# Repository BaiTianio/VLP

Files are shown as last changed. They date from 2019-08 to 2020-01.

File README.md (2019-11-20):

*As we know,VLP is a immature technolgy and involved not only software but hardware, so that's a really complicated project.In here, I just want to show my design for VLP. For others,I know this repository is diffcult to use and understand.If you can get it and interest it,you can contact me with the Issues.* 
# VLP（visible light positioning）
仓库文件目录：  
1.Document：文档 ;  
2.Data_Receive_Process:上位机数据接收和处理数据处理，包括MATLAB和Python,接收到的数据存储在Data子文件下; 
3.Receiver：接收器设计，包括SW模型设计、AD电路设计和STM32程序设计;    
4.Transmitter：发送端设计，包括电路设计和程序设计。

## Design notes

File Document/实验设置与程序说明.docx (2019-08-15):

一、实验:

1.实验设置

LED固定在(x=0cm, y=0cm, z=200cm)。分别将探测器放在:

坐标 | LED与探测器连线的夹角（angle）
(x=0cm, y=35.26cm, z=0cm) | 80°
… | …
(x=0cm, y=346.41cm, z=0cm) | 30°

角度(angle)=(30,31,…,44,45; 46,48,…,78,80).

2.数据处理程序及文件说明：

程序1：singlePD.m

功能：分别绘制单个PD（PD1-PD32），从angle=30°到angle=80°时变化情况。

图坐标：(x：angle从30到80度), (y: 对应光照度)。

生成文件：保存在(picuture/ SignlePD/)文件夹 ,命名规则PDx.jpg (x=1,2…,31,32)。

备注：每次取的是各个PD的最大值。

程序2：PDs8_V1.m

功能:分别绘制，4组PD{(1,5,…,25,29);..;(4,8,…,28,32)}分别在(angle=30,31,…)时的图像。

图坐标：(x：每组PD，1-8)。

生成文件：保存在(./picuture/ 8PDsV1/)文件夹 ,命名规则PDarrayk_l.jpg (k=1,2,3,4; l=angle)。

备注：寻找整个二维数组（确定angle和times了的一次数据）的最大值，然后每个PD取该最大值所在行。

程序3：PDs8_V2.m

功能: 同程序2。

图坐标：同程序2。

生成文件：保存在(./picuture/ 8PDsV2/)文件夹 ,命名规则PDarrayk_l.jpg (k=1,2,3,4; l=angle)。

备注：分别取每个PD所对应的最大值。

程序4：PDs32_V1.m

功能:分别绘制32个PD在(angle=30,31,…)时的图像。

图坐标：(x：32个 PD, 1-32)。

生成文件：保存在(./picuture/ 32PDsV1/)文件夹 ,命名规则Angle_l.jpg (l=angle)。

备注：同程序2

程序5：PDs32_V2.m

功能: 同程序4。

图坐标：同程序4。

生成文件：保存在(./picuture/ 32PDsV2/)文件夹 ,命名规则Angle_l.jpg (l=angle)。

备注：同程序3

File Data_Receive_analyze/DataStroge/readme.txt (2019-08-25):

当前目录命名规则：年_月_日
子目录命名规则：格式_备注，例csv_raw,表示文件为csv格式的原数据

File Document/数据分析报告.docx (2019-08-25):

目前要解决的有两个问题：

1.时间一致性

如果只有一个LED，则所有被照到的PD的数据最大值应出现在同一位置。该问题要解决的是水平角度测量准确性。

2.增益一致性

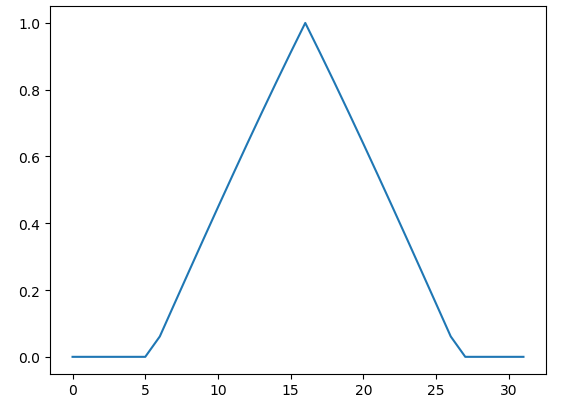
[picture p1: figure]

32个PD分布应该接近理想的分布曲线（图1）。该问题决定了俯仰角测量准确性。

图1 理想分布

一、问题1的分析

已知条件：

ADC时钟12MHz,采样时间239.5cycle，转换时间=采样时间+12.5cycle。每个通道的转换时间为(239.5+12.5)/12=21us。图2所示为不同PD采样时间分布，其中颜色条为以PD0为0时刻的延迟时间。由图可以看出32个PD转换完需要651us。32个PD转换完成后会进行数据发送给上位机，数据发送时间不确定。

图2 采集时间分布

数据分析：

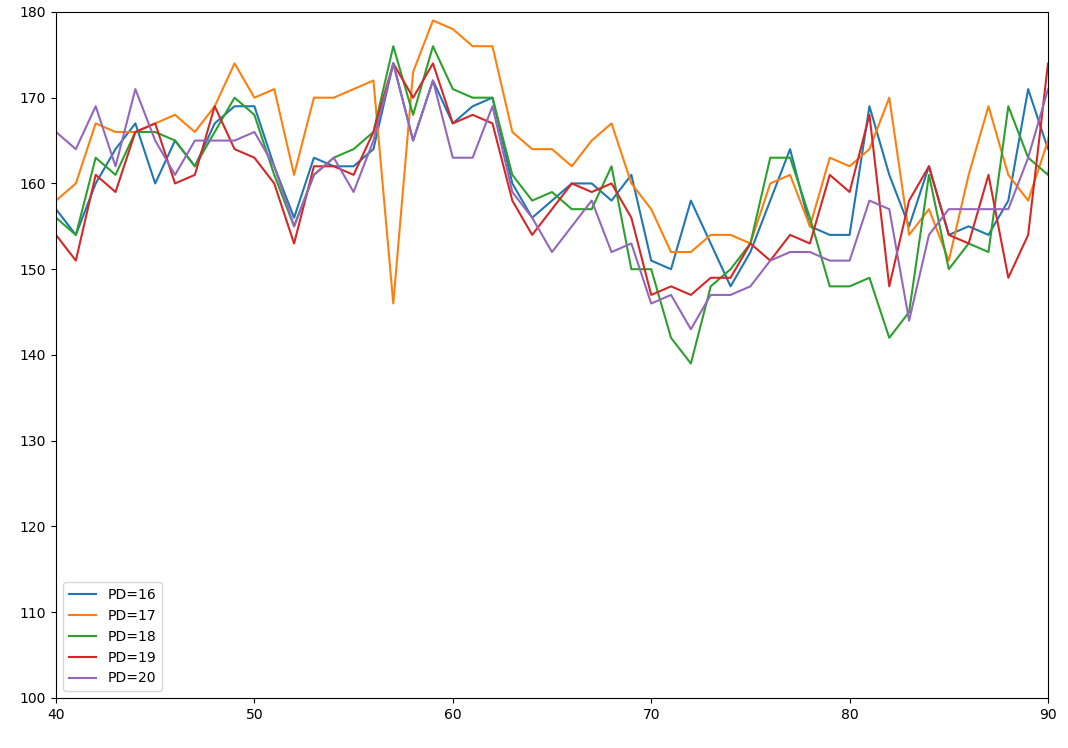
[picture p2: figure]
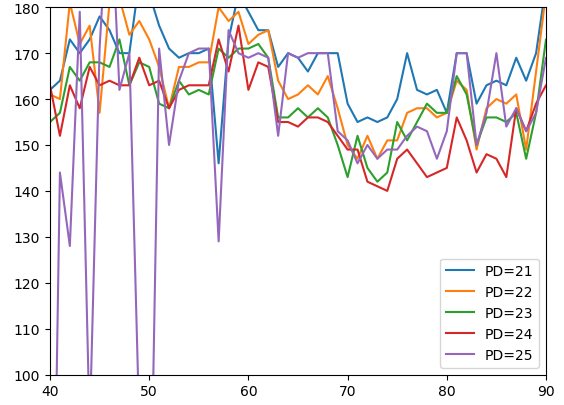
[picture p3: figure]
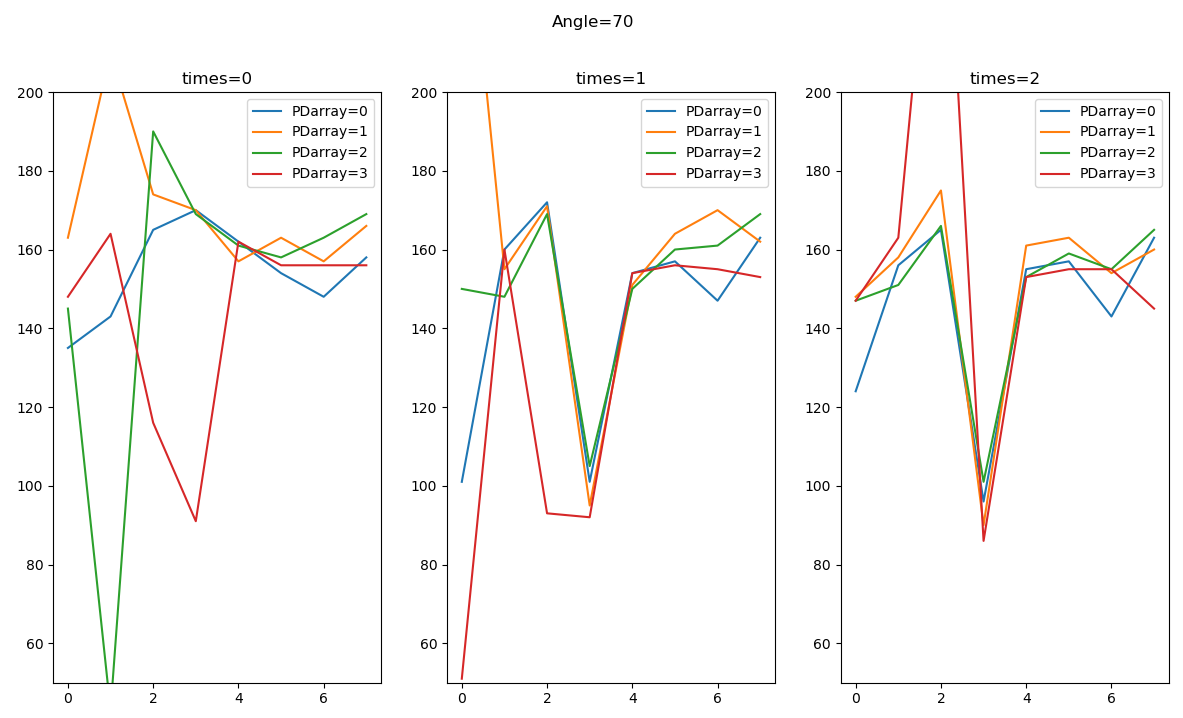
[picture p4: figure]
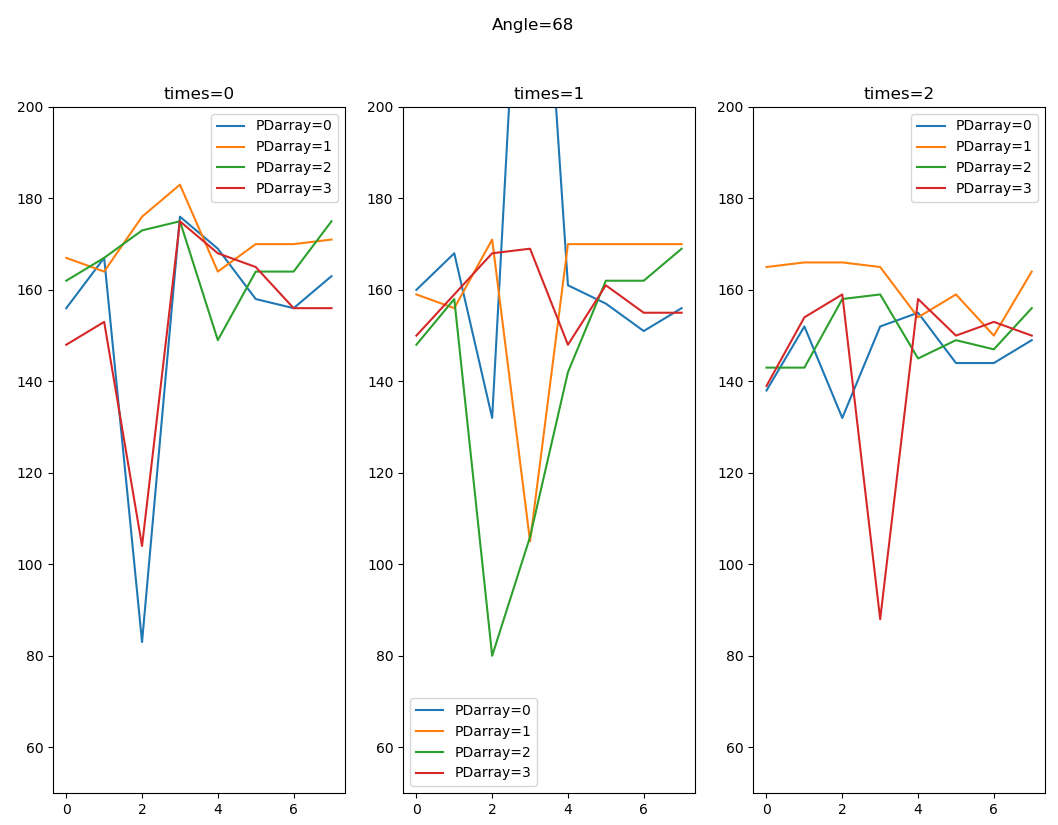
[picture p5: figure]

如图3所示，分别为68度时和70度时每组PD最大值所处的位置曲线。图4是单个PD在所有数据中的位置曲线。

图4 单个PD的在所有数据中的位置分布

图3 每组PD最大值位置曲线

根据图3、4可以看出，不同PD之间的关系比较明确，同一PD之间的变化关系不明确。以图3右图中PD21和PD22为例，PD21曲线处于PD22上方，分析原因有二：1.转换时间差的影响；2.PD朝向不同。

二、问题2的分析

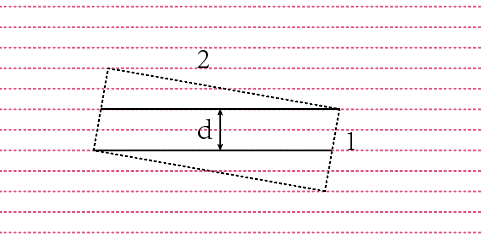
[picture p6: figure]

已知条件：图5是PD和其对应的角度关系。对PD受光照情况进行近似模拟，以图6中d的大小代表光照大小即可得出图一的分布曲线。

图5. PD与对应角度

图6. PD光照情况

数据分析：

图7分别为未调整增益和调整增益后的数据图。

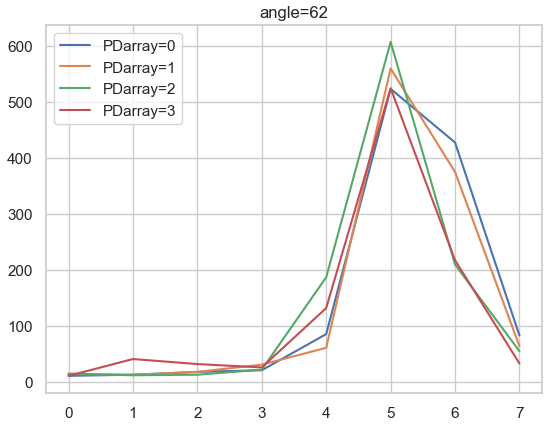
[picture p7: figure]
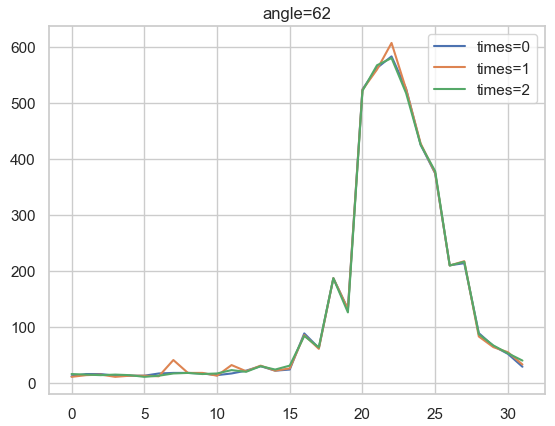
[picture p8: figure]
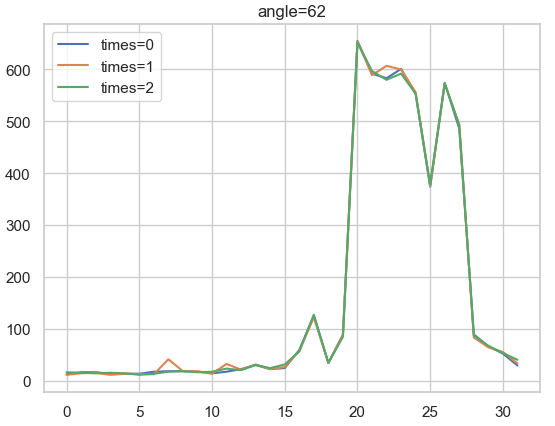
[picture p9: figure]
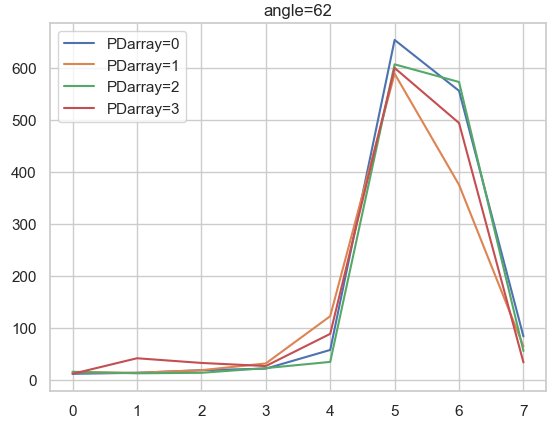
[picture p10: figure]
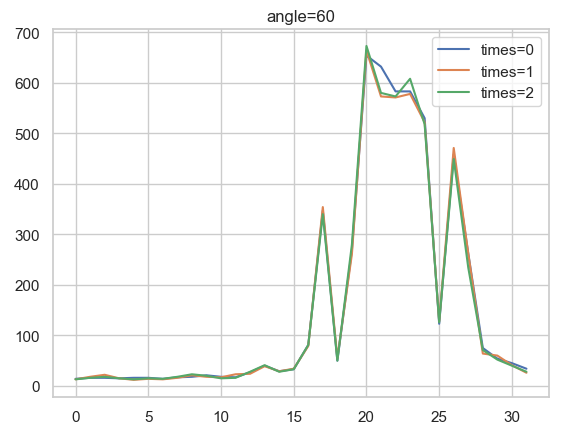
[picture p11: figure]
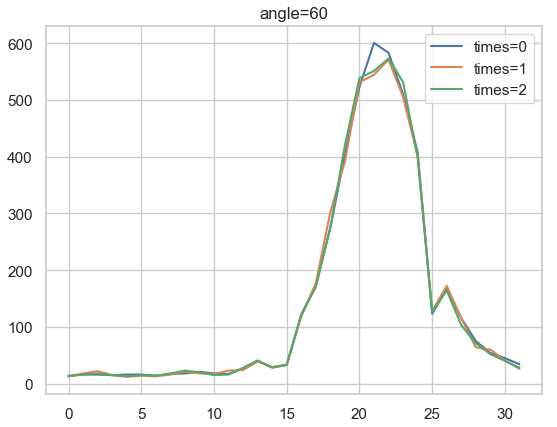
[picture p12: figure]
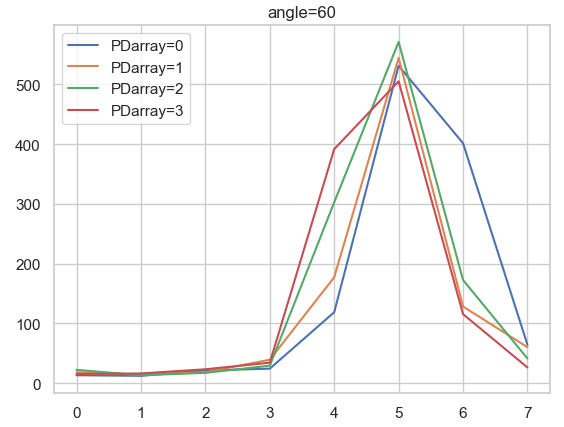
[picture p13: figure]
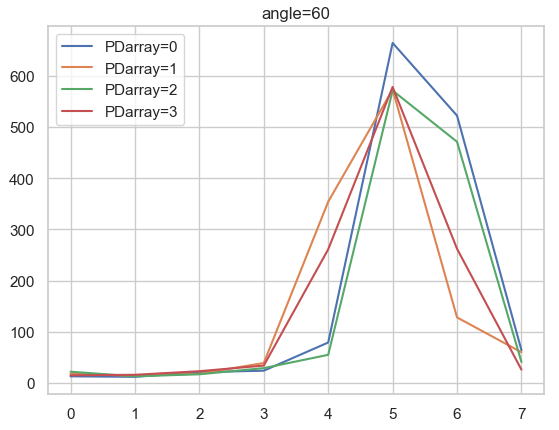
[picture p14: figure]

62°调整前

60°调整后

60°调整前

62°调整后

图7. 增益调整

三.结论和计划

第2个问题经过增益调整后可以改善，但是PD增益调整后对不同角度的效果不同，需要寻找最优解。可转化为寻找以下问题的最优解：

第1个问题，规律变化有随机性，但是变化范围不大，可以通过取均值进行改善。

影响上述两个问题的原因：1.PD角度朝向不准确；2.旋转不稳定。两种原因混合使问题变得复杂。

计划：除了进行对数据进行处理外，针对问题1设置实验装置，解决装置固有问题对增益带来的影响。

二、实验二

0 | 15
1 | 17
2 | 19
3 | 21
4 | 23
5 | 25
6 | 27
7 | 29
8 | 31
9 | 33
10 | 35
11 | 37
12 | 39
13 | 41
14 | 43
15 | 45
16 | 47
17 | 49
18 | 51
19 | 53
20 | 55
21 | 57
22 | 59
23 | 61
24 | 63
25 | 65
26 | 67
27 | 69
28 | 71
29 | 73
30 | 75
31 | 77
32 | 79

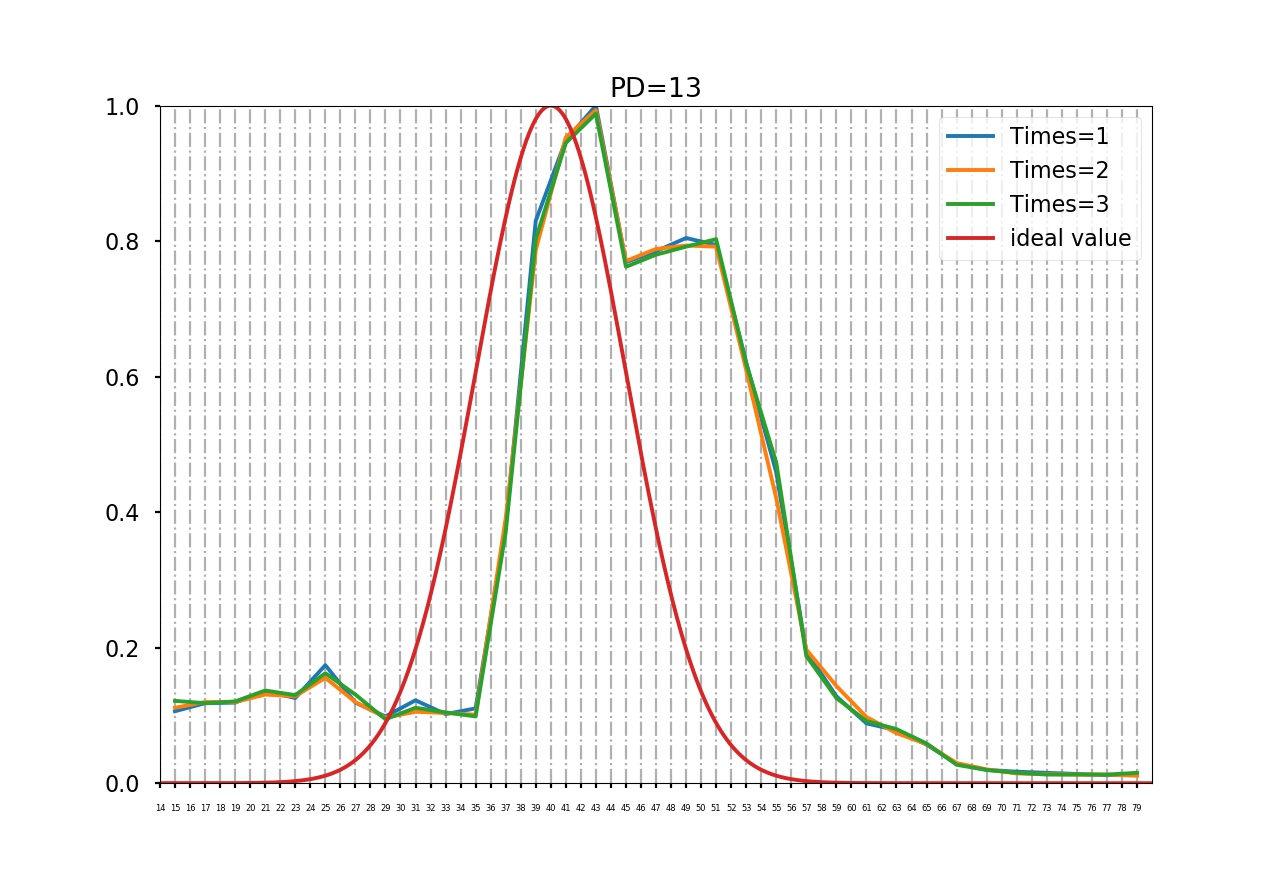
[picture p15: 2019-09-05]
Data_Receive_analyze/Analyze_Python/2019_8_23实验分析/俯仰角/解决方法1/Picture/singlePD/PD13.jpg

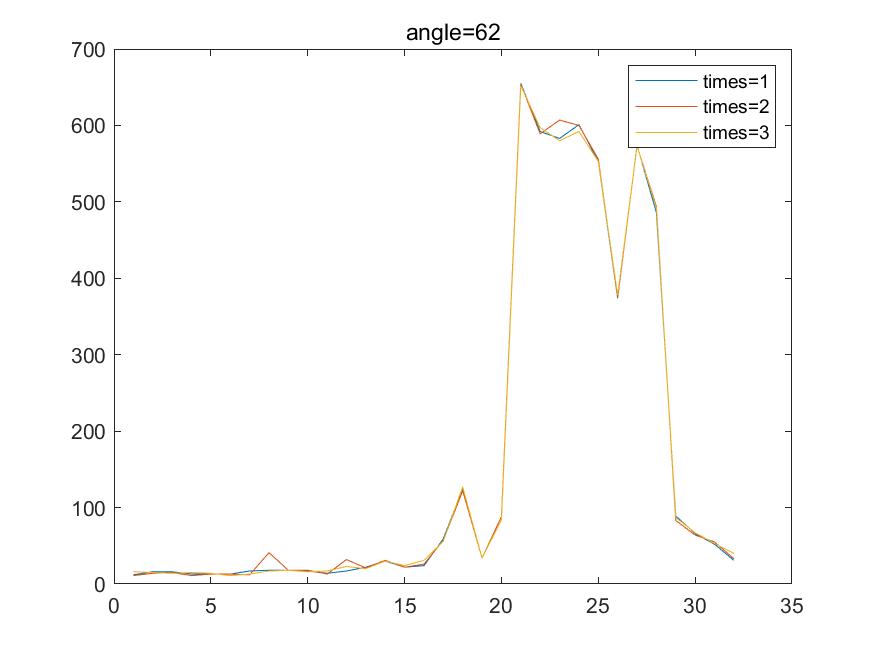
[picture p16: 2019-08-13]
Data_Receive_analyze/Analyze_Matlab/picture/32PDsV2/Angle_62.jpg

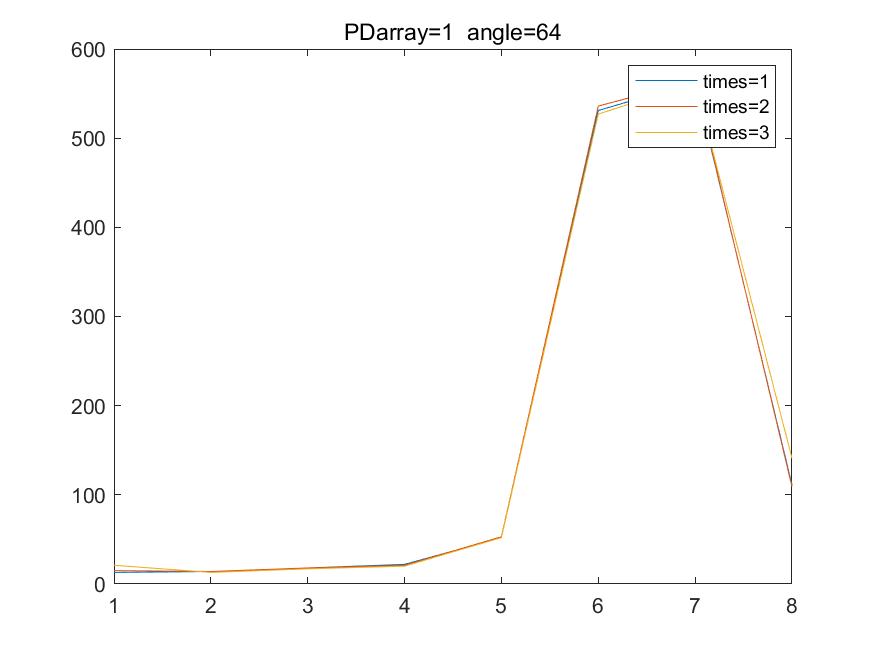
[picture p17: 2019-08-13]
Data_Receive_analyze/Analyze_Matlab/picture/8PDsV2/PDarray1_64.jpg

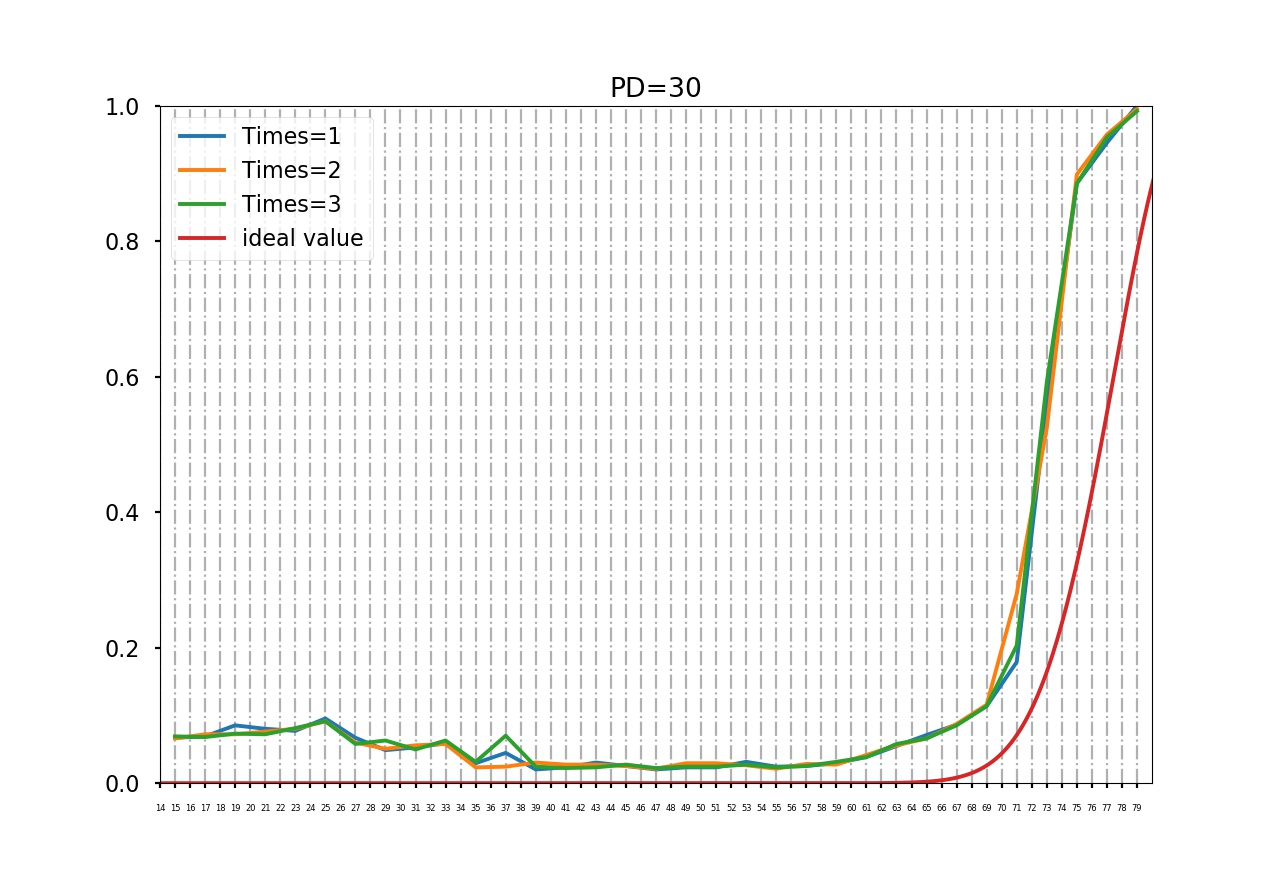
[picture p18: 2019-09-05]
Data_Receive_analyze/Analyze_Python/2020_1_13实验分析/俯仰角/解决方法1/Picture/singlePD/PD30.jpg

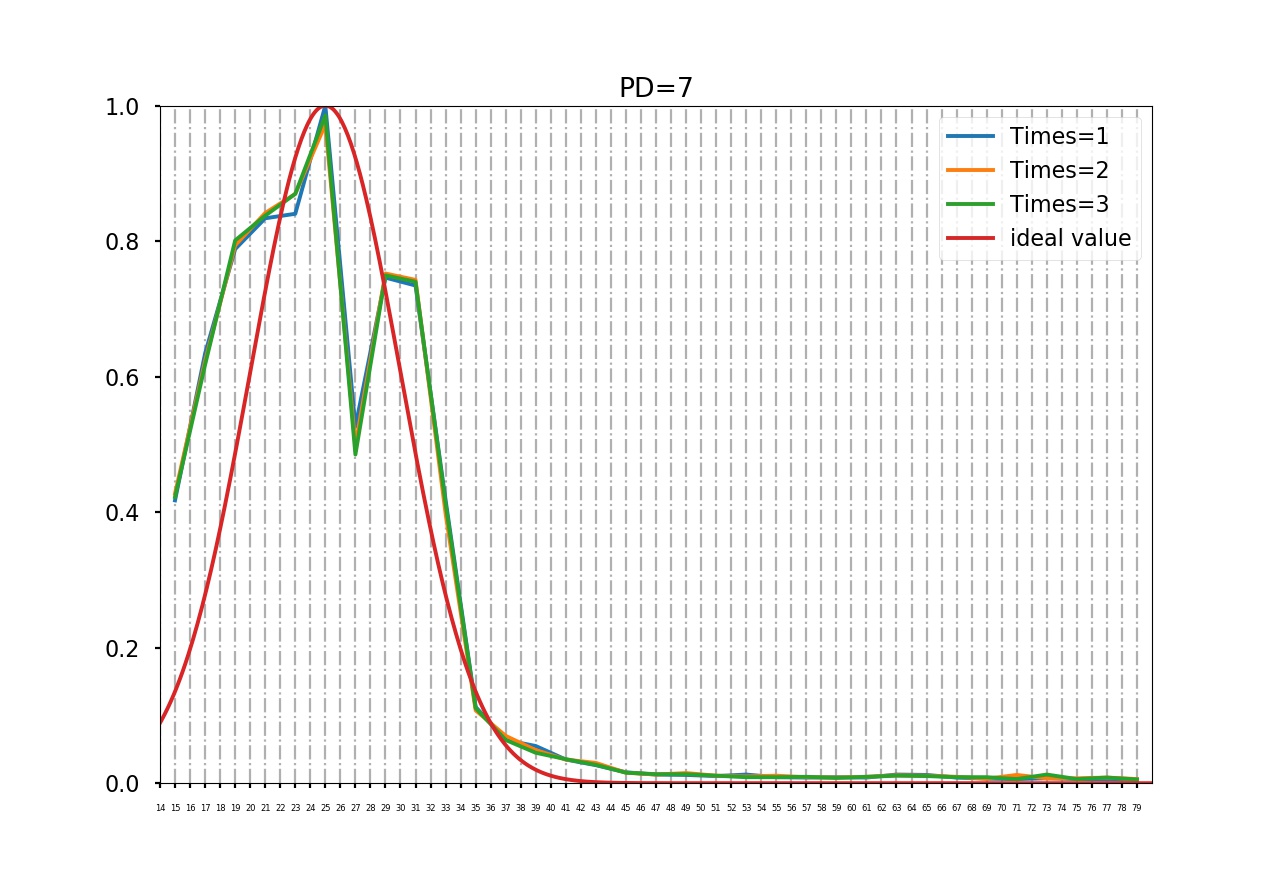
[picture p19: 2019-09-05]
Data_Receive_analyze/Analyze_Python/2020_1_13实验分析/俯仰角/解决方法1/Picture/singlePD/PD7.jpg

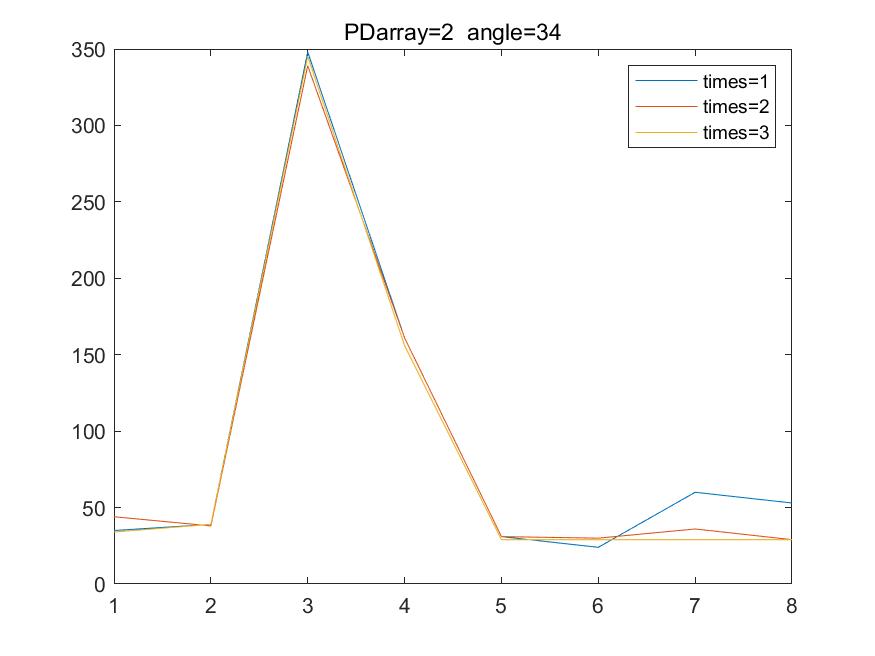
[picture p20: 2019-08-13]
Data_Receive_analyze/Analyze_Matlab/picture/8PDsV2/PDarray2_34.jpg

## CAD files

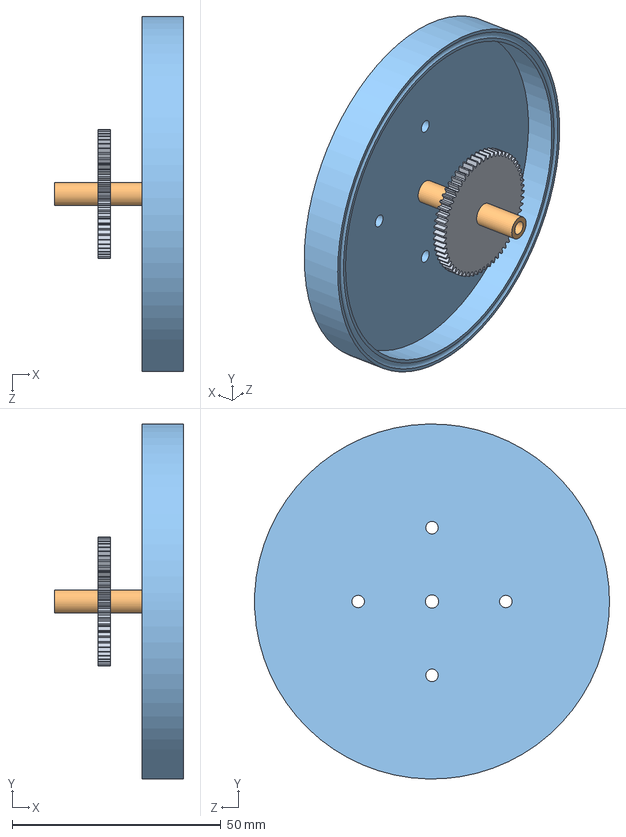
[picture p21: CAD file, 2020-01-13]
Receiver/Construction_Design(SW)/转台/V3/上盖.SLDASM
31.0 x 85.0 x 85.0 mm
4号齿轮Part_a
4号齿轮Part_b
上盖Part_a

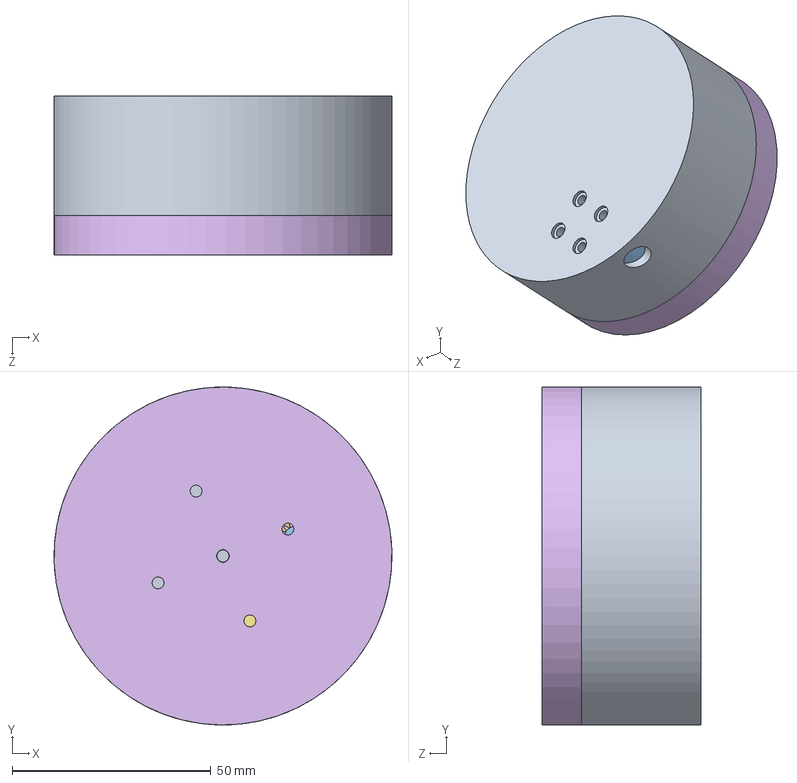
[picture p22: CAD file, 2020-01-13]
Receiver/Construction_Design(SW)/转台/V3/组合体.SLDASM
85.0 x 85.0 x 40.0 mm
底座
滚珠 x 10
电机
1号齿轮Part_a
1号齿轮Part_b
2号齿轮Part_a
2号齿轮Part_b
2号齿轮Part_c
3号齿轮Part_a
3号齿轮Part_b
3号齿轮Part_c
4号齿轮Part_a
4号齿轮Part_b
上盖Part_a

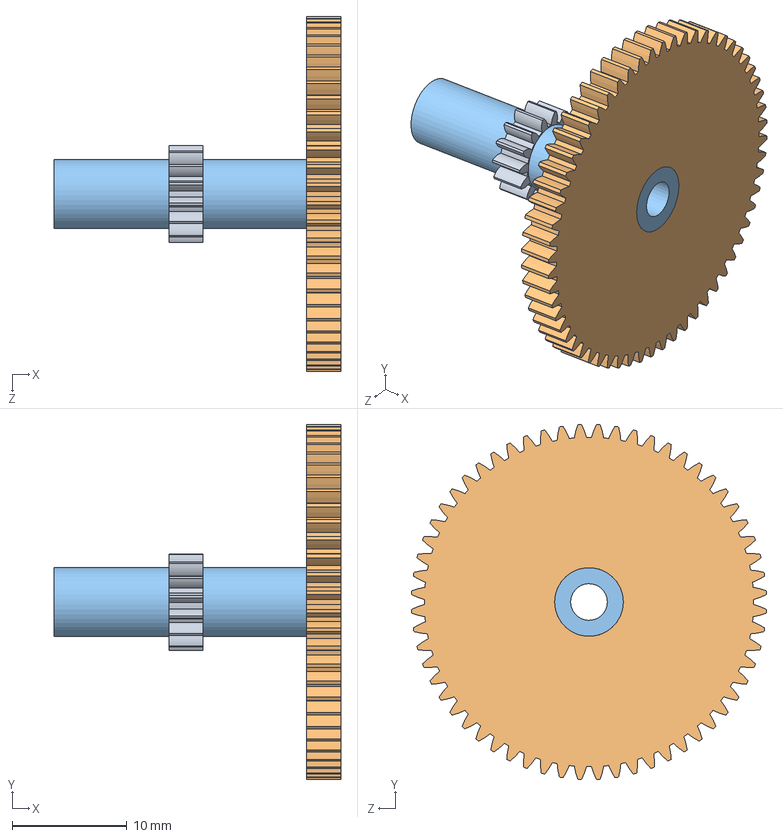
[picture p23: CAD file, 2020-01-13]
Receiver/Construction_Design(SW)/转台/V3/齿轮/2号齿轮.SLDASM
25.0 x 31.0 x 31.0 mm
2号齿轮Part_a
2号齿轮Part_b
2号齿轮Part_c

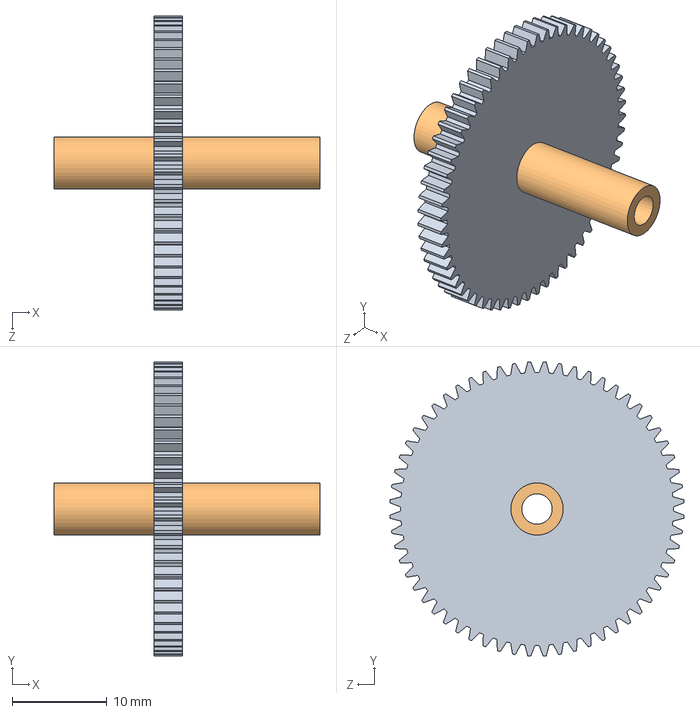
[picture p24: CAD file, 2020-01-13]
Receiver/Construction_Design(SW)/转台/V3/齿轮/4号齿轮(上盖).SLDASM
28.0 x 31.0 x 31.0 mm
4号齿轮Part_a
4号齿轮Part_b

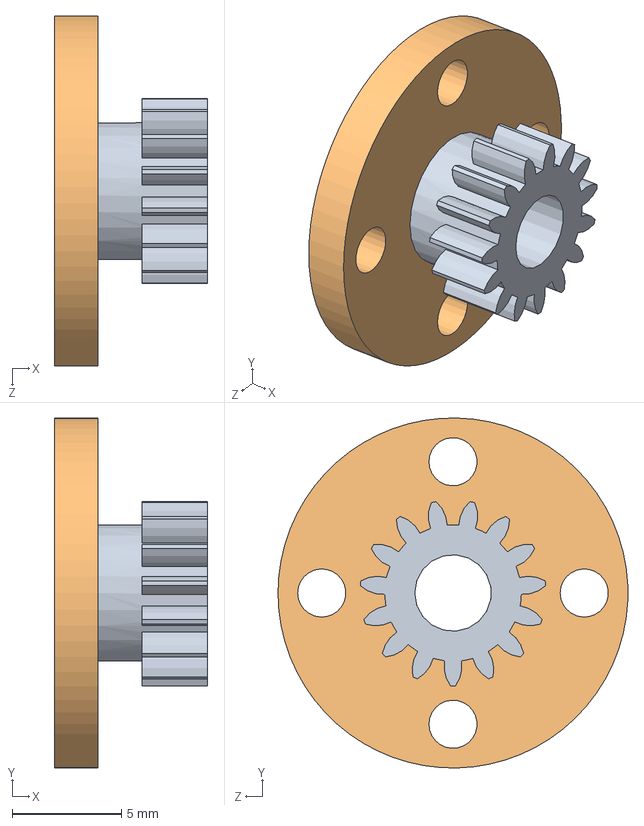
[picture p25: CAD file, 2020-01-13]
Receiver/Construction_Design(SW)/转台/V3/齿轮/1号齿轮.SLDASM
7.00 x 16.0 x 16.0 mm
1号齿轮Part_a
1号齿轮Part_b

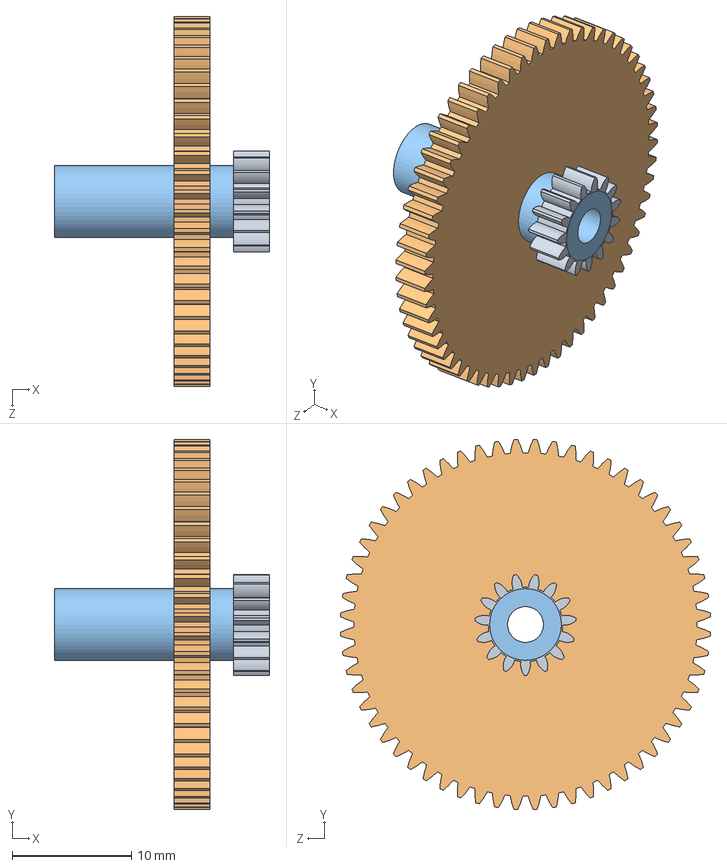
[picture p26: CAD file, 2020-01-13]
Receiver/Construction_Design(SW)/转台/V3/齿轮/3号齿轮.SLDASM
18.0 x 31.0 x 31.0 mm
3号齿轮Part_a
3号齿轮Part_b
3号齿轮Part_c

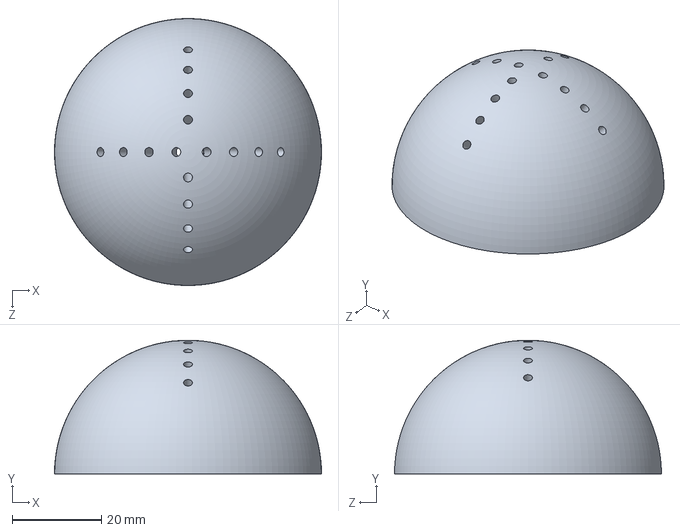
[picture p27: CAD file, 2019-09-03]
Receiver/Construction_Design(SW)/V2/传感器部分/16PD.SLDPRT
60.0 x 30.0 x 60.0 mm

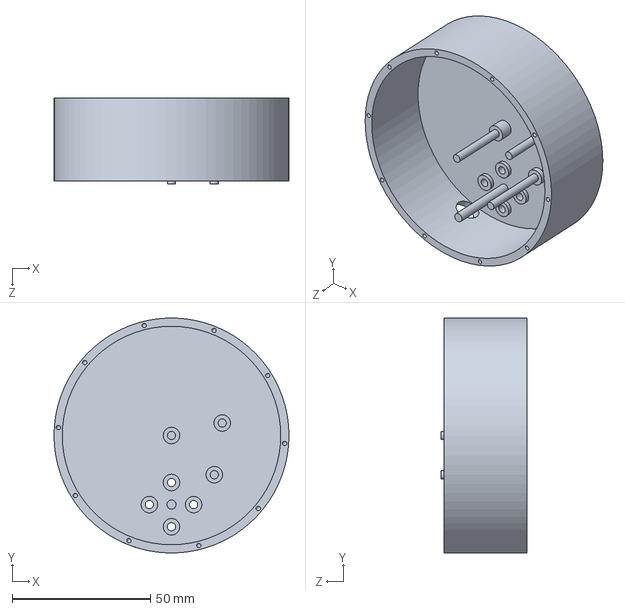
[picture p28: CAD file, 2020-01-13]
Receiver/Construction_Design(SW)/转台/V3/底座.SLDPRT
85.0 x 84.9 x 31.0 mm

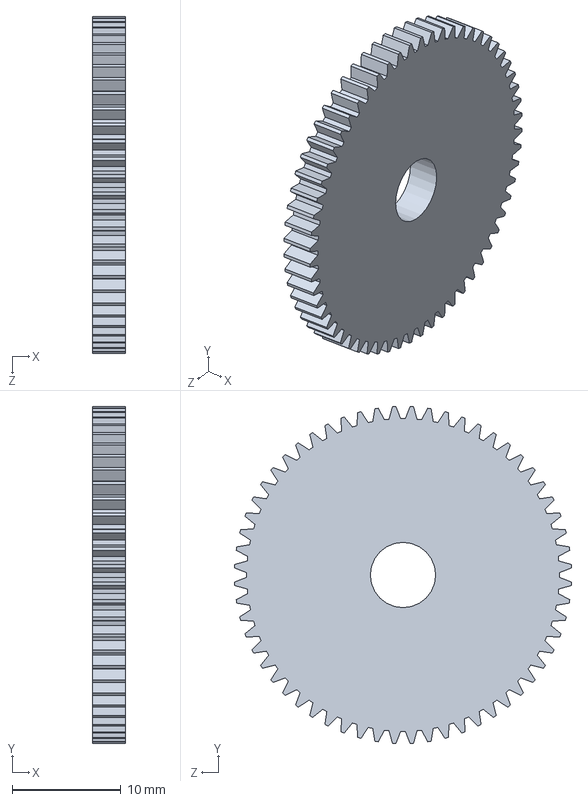
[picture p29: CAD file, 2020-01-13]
Receiver/Construction_Design(SW)/转台/V3/齿轮/2号齿轮Part_b.SLDPRT
3.00 x 31.0 x 31.0 mm

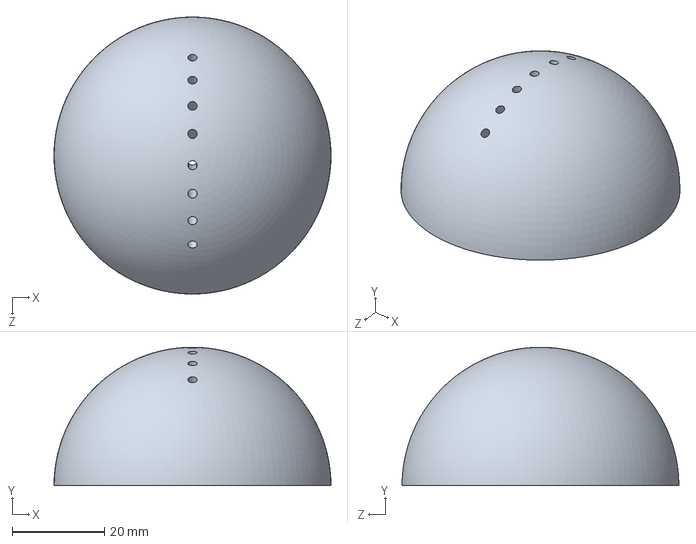
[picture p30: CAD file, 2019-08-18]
Receiver/Construction_Design(SW)/V2/传感器部分/8PD.SLDPRT
60.0 x 30.0 x 60.0 mm

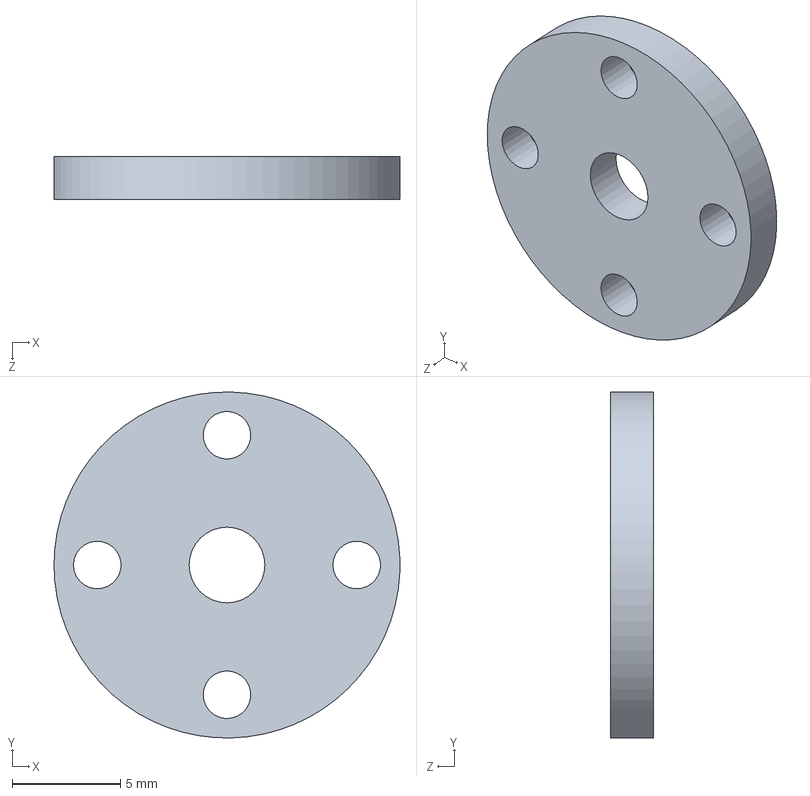
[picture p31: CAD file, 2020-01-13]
Receiver/Construction_Design(SW)/转台/V3/齿轮/1号齿轮Part_b.SLDPRT
16.0 x 16.0 x 2.00 mm

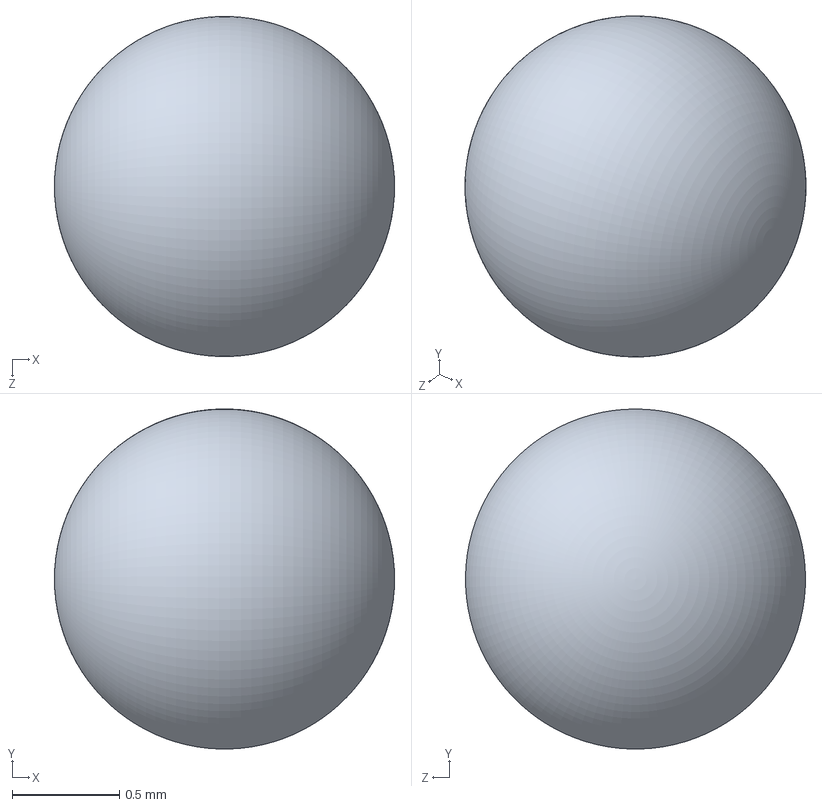
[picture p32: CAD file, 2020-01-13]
Receiver/Construction_Design(SW)/转台/V3/滚珠.SLDPRT
1.59 x 1.59 x 1.59 mm

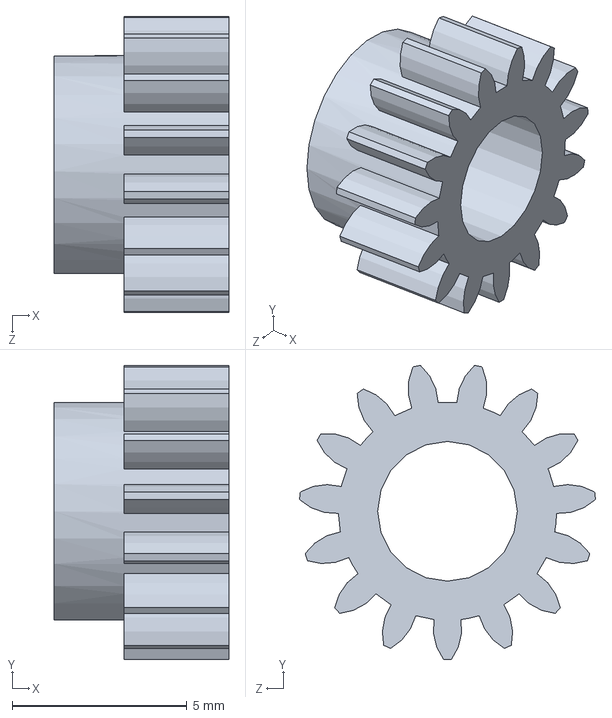
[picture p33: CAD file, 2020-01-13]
Receiver/Construction_Design(SW)/转台/V3/齿轮/1号齿轮Part_a.SLDPRT
5.00 x 8.43 x 8.47 mm

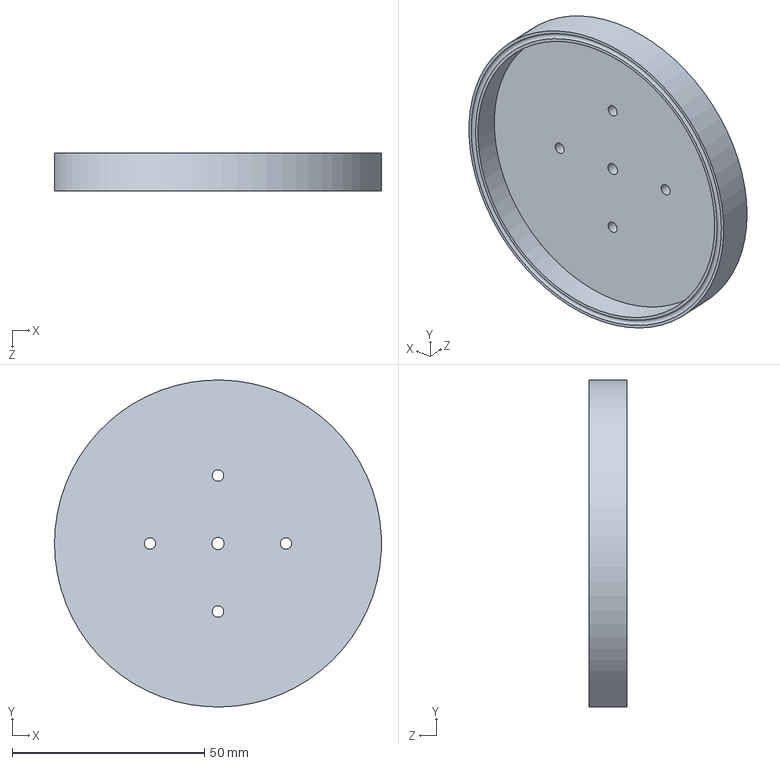
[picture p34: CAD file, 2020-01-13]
Receiver/Construction_Design(SW)/转台/V3/上盖Part_a.SLDPRT
85.0 x 85.0 x 10.0 mm

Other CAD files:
Receiver/Construction_Design(SW)/转台/V3/电机.SLDPRT
Receiver/Construction_Design(SW)/转台/V3/齿轮/4号齿轮Part_a.SLDPRT
Receiver/Construction_Design(SW)/转台/V3/齿轮/3号齿轮Part_a.SLDPRT
Receiver/Construction_Design(SW)/V1/主体.SLDPRT
Receiver/Construction_Design(SW)/V1/传感器.SLDPRT
Receiver/Construction_Design(SW)/V1/信号处理与通讯电路.SLDPRT
Receiver/Construction_Design(SW)/V1/减速电机.SLDPRT
Receiver/Construction_Design(SW)/V1/动力盒.SLDPRT
Receiver/Construction_Design(SW)/V1/底座.SLDPRT
Receiver/Construction_Design(SW)/V1/无线模块.SLDPRT
Receiver/Construction_Design(SW)/V1/灯泡.SLDPRT
Receiver/Construction_Design(SW)/V1/电源模块.SLDPRT
Receiver/Construction_Design(SW)/V2/传感器部分/16PD.SLDDRW
Receiver/Construction_Design(SW)/转台/V1/上盖.SLDASM
Receiver/Construction_Design(SW)/转台/V1/上盖零件.SLDPRT
Receiver/Construction_Design(SW)/转台/V1/底座.SLDPRT
Receiver/Construction_Design(SW)/转台/V1/打印文件/1号齿轮.STEP
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

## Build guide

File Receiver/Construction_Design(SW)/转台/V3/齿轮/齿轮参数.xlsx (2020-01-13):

 | 1号齿轮 | 2号齿轮 |  | 3号齿轮 |  | 上盖齿轮
 |  | 大齿 | 小齿 | 大齿 | 小齿
模数 | 0.8 | 0.8 | 0.8 | 0.8 | 0.8 | 0.8
齿数 | 10 | 30 | 10 | 40 | 10 | 38
压力角 | 20 | 20 | 20 | 20 | 20 | 20
面宽 | 2 | 2 | 2 | 2 | 2 | 2

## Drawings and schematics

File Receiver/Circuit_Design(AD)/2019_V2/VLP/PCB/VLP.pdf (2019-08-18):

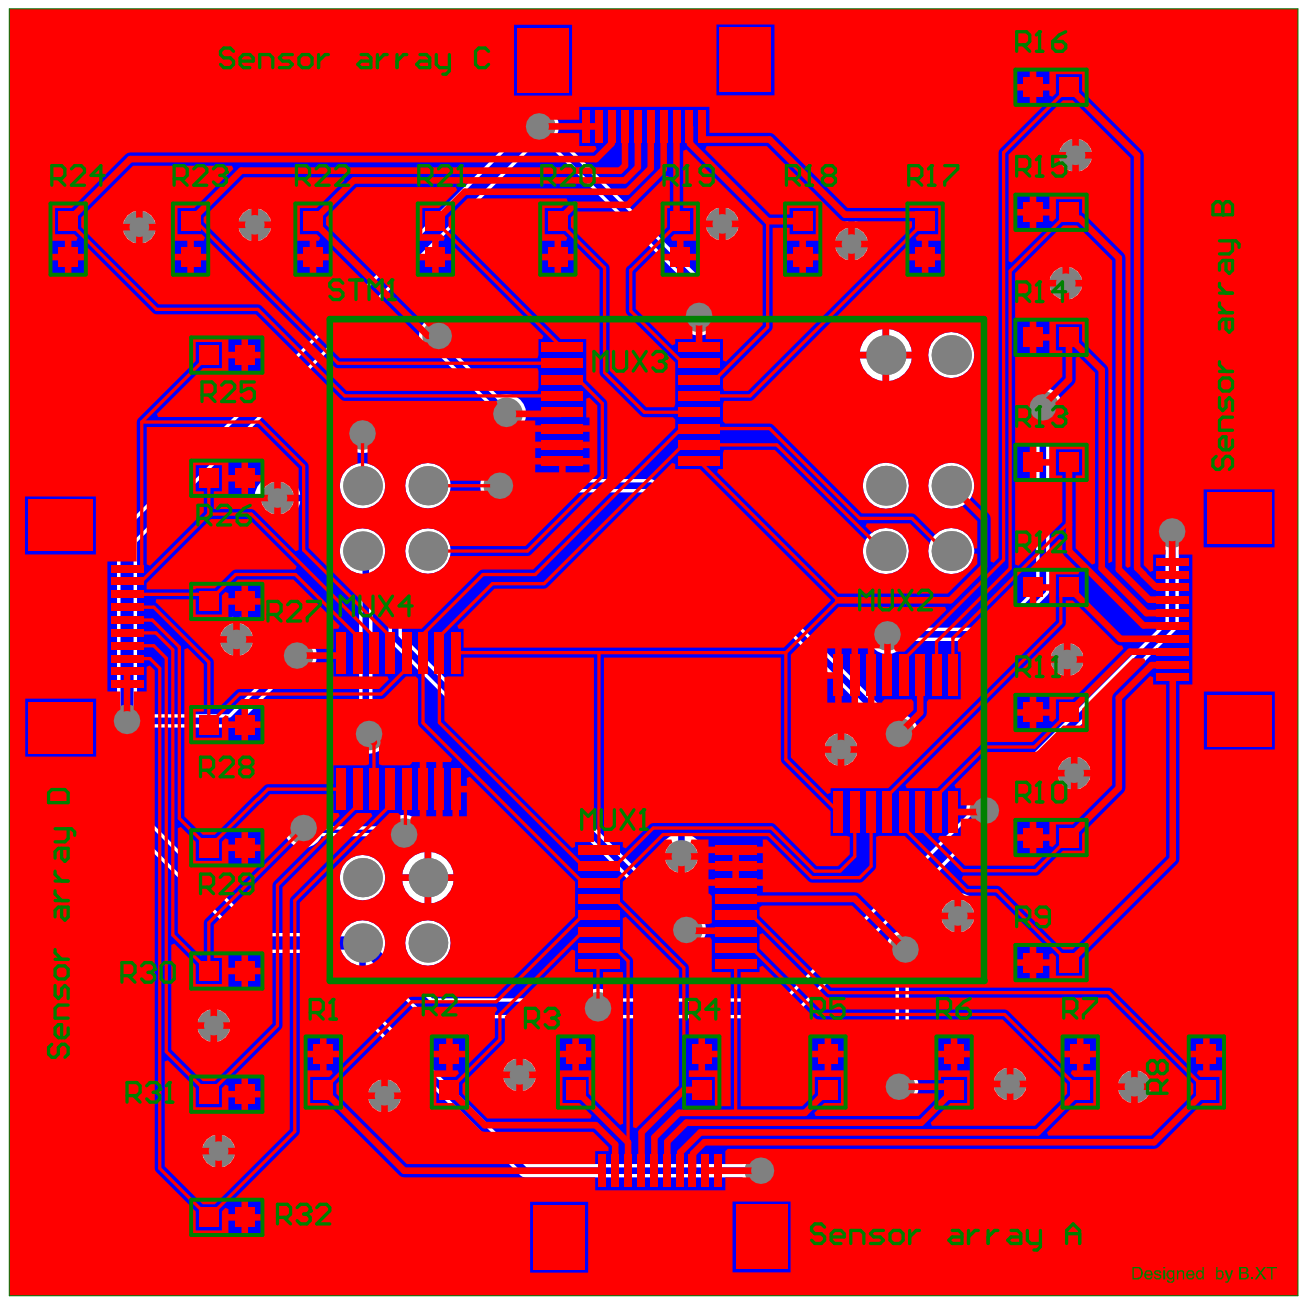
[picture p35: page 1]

Board Stack Report

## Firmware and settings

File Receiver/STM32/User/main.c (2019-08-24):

#include "sys.h"
#include "usart.h"
#include "delay.h"
#include "adc.h"
#include "gpio.h"
#include "exti.h"

u16 Data_storge[40]={0};//数据存储

void Get_ADC(u16 *data_point)//获取ADC信息，并保存到data_storge
{
	u16 temp;//临时存储ADC数据
	int Channel=0;
	u8 Sensor_g;
	//u8 Data[8];
	
	for(Sensor_g=0;Sensor_g<8;Sensor_g++)
		{       
			GPIO_Write(GPIOB,Sensor_g<<3);//控制模拟选择器
			delay_us(5);
			*data_point=Sensor_g;
			for(Channel=0;Channel<=3;Channel++)
				{
					temp=Get_Adc_Average(Channel,5);//每个通道转换5次求均值	
				  *(++data_point)=temp;
				}
			data_point++;//为sensor_g增加地址
		}
}

int main(void)
{	
	uart_init(1500000);
	delay_init();
	Adc_Init(); 
	gpio_Init();
	exti_init();
	while(1)
	{
		Get_ADC(Data_storge);//采集数据	
		for (int i=0;i<40;i++)
			{
				while(USART_GetFlagStatus(USART1,USART_FLAG_TC)!=1);
				USART_SendData(USART1,Data_storge[i]);
			}
	}
}

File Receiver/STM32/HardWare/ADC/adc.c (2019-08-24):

 #include "adc.h"
 #include "delay.h"
		   
//初始化ADC
//这里我们仅以规则通道为例
//我们默认将开启通道0~3																	   
void  Adc_Init(void)
{ 	
	ADC_InitTypeDef ADC_InitStructure; 
	GPIO_InitTypeDef GPIO_InitStructure;

	RCC_APB2PeriphClockCmd(RCC_APB2Periph_GPIOA |RCC_APB2Periph_ADC1	, ENABLE );	  //使能ADC1通道时钟
 

	RCC_ADCCLKConfig(RCC_PCLK2_Div6);   //设置ADC分频因子6 72M/6=12,ADC最大时间不能超过14M

	//PA1 作为模拟通道输入引脚                         
	GPIO_InitStructure.GPIO_Pin = GPIO_Pin_0 | GPIO_Pin_1 | GPIO_Pin_2 |GPIO_Pin_3;
	GPIO_InitStructure.GPIO_Mode = GPIO_Mode_AIN;		//模拟输入引脚
	GPIO_Init(GPIOA, &GPIO_InitStructure);	

	ADC_DeInit(ADC1);  //复位ADC1 

	ADC_InitStructure.ADC_Mode = ADC_Mode_Independent;	//ADC工作模式:ADC1和ADC2工作在独立模式
	ADC_InitStructure.ADC_ScanConvMode = DISABLE;	//模数转换工作在单通道模式
	ADC_InitStructure.ADC_ContinuousConvMode = DISABLE;	//模数转换工作在单次转换模式
	ADC_InitStructure.ADC_ExternalTrigConv = ADC_ExternalTrigConv_None;	//转换由软件而不是外部触发启动
	ADC_InitStructure.ADC_DataAlign = ADC_DataAlign_Right;	//ADC数据右对齐
	ADC_InitStructure.ADC_NbrOfChannel = 1;	//顺序进行规则转换的ADC通道的数目
	ADC_Init(ADC1, &ADC_InitStructure);	//根据ADC_InitStruct中指定的参数初始化外设ADCx的寄存器   

  
	ADC_Cmd(ADC1, ENABLE);	//使能指定的ADC1
	
	ADC_ResetCalibration(ADC1);	//使能复位校准  
	 
	while(ADC_GetResetCalibrationStatus(ADC1));	//等待复位校准结束
	
	ADC_StartCalibration(ADC1);	 //开启AD校准
 
	while(ADC_GetCalibrationStatus(ADC1));	 //等待校准结束
 
//	ADC_SoftwareStartConvCmd(ADC1, ENABLE);		//使能指定的ADC1的软件转换启动功能

}				  
//获得ADC值
//ch:通道值 0~3
u16 Get_Adc(u8 ch)   
{
  	//设置指定ADC的规则组通道，一个序列，采样时间
	ADC_RegularChannelConfig(ADC1, ch, 1, ADC_SampleTime_71Cycles5);	//ADC1,ADC通道,采样时间为239.5周期	  			    
  
	ADC_SoftwareStartConvCmd(ADC1, ENABLE);		//使能指定的ADC1的软件转换启动功能	
	 
	while(!ADC_GetFlagStatus(ADC1, ADC_FLAG_EOC ));//等待转换结束

	return ADC_GetConversionValue(ADC1);	//返回最近一次ADC1规则组的转换结果
}

u16 Get_Adc_Average(u8 ch,u8 times)
{
	u32 temp_val=0;
	u8 t;
	for(t=0;t<times;t++)
	{
		temp_val+=Get_Adc(ch);
		//delay_ms(5);
	}
	return temp_val/times;
} 	 

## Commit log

2019-08-13 first create
    [PD分布.xlsx, data_30_1.csv, data_30_2.csv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]
2019-08-15 日常修改
2019-08-15 修改stm32文件
2019-08-18 文件结构重新整理分为：发送、接收、数据处理、文档
    [PD分布.xlsx, data_30_1.csv, data_30_2.csv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]
2019-08-18 文件夹调整
2019-08-18 说明文件修改
    [PD分布.xlsx]
2019-08-18 修改说明文件
2019-08-18 整理文件
    [16PD.SLDPRT, 8PD.SLDDRW, 8PD.SLDPRT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]
2019-08-22 调整文件夹命名，更改python wifi接收绑定以解决linux下addr has been used问题
    [data_30_1.csv, data_30_2.csv, data_30_3.csv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]
2019-08-23 修改接收器模型
    [16PD.SLDPRT]
2019-08-23 采集的新数据保存
    [16PD.SLDPRT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]
2019-08-24 数据处理
    [data_15_0.csv, data_15_1.csv, data_15_2.csv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]
2019-08-25 日常处理数据
    [data_15_0.csv, data_15_1.csv, data_15_2.csv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]
2019-08-25 日常处理数据，尝试用高斯函数校正数据
    [data_61_1.csv]
2019-08-28 处理数据绘图
2019-08-29 实验了相似度计算方法，效果很好
    [16PD.SLDPRT]
2019-08-30 调整文件结构
    [data_30_1.csv, data_30_2.csv, data_30_3.csv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]
2019-08-31 日常处理数据绘图
2019-09-02 水平角的分析
2019-09-02 删除无用的文件
2019-09-02 绘制水平角分布图+文件夹调整
2019-09-03 优化程序
2019-09-04 整理数据文件
    [data_15_0.csv, data_15_1.csv, data_15_2.csv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]
2019-09-05 修改数据处理程序，生成增益调整后数据
    [data_15_1.csv, data_15_2.csv, data_15_3.csv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]
2019-09-14 方案一处理
    [PD0_1.csv, PD0_2.csv, PD0_3.csv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]
2019-09-15 水平角方案
    [data_15_1.csv, data_15_2.csv, data_15_3.csv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]
2019-09-17 最小二乘方法
    [data_15_1.csv, data_15_2.csv, data_15_3.csv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]
2019-10-09 终于把线性回归弄好了，开心
    [data_15_0.csv, data_15_1.csv, data_15_2.csv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]
2019-10-28 水平角处理
    [data_35_1.csv, data_35_2.csv, data_35_3.csv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]
2019-10-30 水平角算法
2019-11-20 “转台设计
    [16PD.SLDDRW, 16PD.SLDPRT, 1号齿轮.SLDASM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]
2020-01-13 实验前同意提交
    [16PD.SLDDRW, 16PD.SLDPRT, 1号齿轮.SLDASM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]
2020-01-13 WIFI接收修改
2020-01-13 1月13日采集数据上传
    [PD0_1.csv, PD0_2.csv, PD0_3.csv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]
2020-01-14 14号采集数据
2020-01-19 数据预处理程序修改
2020-01-31 俯仰角处理
    [data_15_1.csv, data_15_2.csv, data_15_3.csv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]
2020-02-04 水平角测量
    [(100,-10)_0.csv, (100,-10)_1.csv, (100,-10)_2.csv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]
